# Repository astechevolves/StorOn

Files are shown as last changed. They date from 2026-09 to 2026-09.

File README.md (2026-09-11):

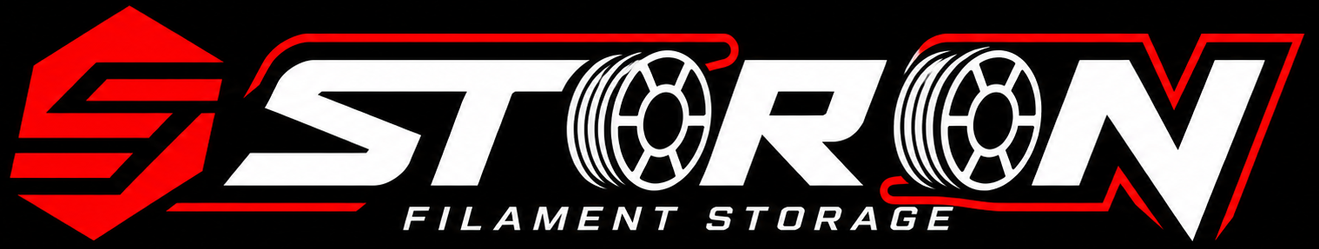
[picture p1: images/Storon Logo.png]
Storon Logo

Name credit to u/akir3y on reddit and chosen based on upvotes.

This project is a Voron printer stand that also stores filament. You have options for active dehumditifcation as well as the ability to feed your Voron (or any other printer really...) from within the stand using a [Filamentalist](https://github.com/Carrot-collective/ERCF_v2/tree/master/Recommended_Options/Filamentalist_Rewinder/Filamentalist_FV3_Rewinder) passive rewinder and an [lll-plus](https://mellow.klipper.cn/en/docs/category/fly-lll-plus-%E7%BC%93%E5%86%B2%E5%99%A8) buffer.

This is rev 1 and i have lots of ideas for what it could be. I am current working on the BOM for the build as it stand and getting the models made so far prepped for upload. 

At the dimensions used for my build there can be up to 14 spools on each drawer and i have 2 drawers installed for a total of 28 spools of storage. I have 5 spools across the top for the toolheads and the buffers are mounted below them. Using [custom lll-plus firmware](https://github.com/astechevolves/lll-buffed) with I2C controls i am connecting a single USB cable to the RasPi running klipper and controlling/monitoring the buffers. 

Some used parts:\
Rack Slides: I did not purchase any as i had some on hand. If i build another one ill need to buy some to test fits. \
2020 Aluminum Extrusion: https://a.co/d/0fAiQeXf \
2040 Aluminum Extrusion: https://a.co/d/03j1iFax \
Corner Brackets: https://a.co/d/0c3Umoue \
3 Side Corners: https://a.co/d/0ic4IAEs \
Profile L Brackets: https://a.co/d/0b12QCzn \
M5 Nuts and Screws: https://a.co/d/0fcr5ywm \
Sealing Foam: https://a.co/d/0fpPBf9j

Hardware for [Clicky Clack Door](https://github.com/tanaes/whopping_Voron_mods/blob/main/clickyclacky_door%2FREADME.md). Used 3 hinges instead of two and the door panel and sealing was longer for the larger door.  

Pin Bushings for Clicky Clack: https://a.co/d/01oHRWRj

If you want monitoring some ESP32 hardware will likely be needed too. How you monitor that data may change. I am publishing MQTT updates to Home Assistant. 

Power supply for dehumidifier, 3VDC required: https://a.co/d/0h5Y2pVP \
MDL-5 Dehumdifier: https://micro-dehumidifier.com/products-rosahl/membranes/ \
Wiring Break out for I2C Buss on Buffers: https://a.co/d/03XT3YTJ

PTFE Connectors: https://a.co/d/0i8aAcsk

[LLL-Plus Buffer](https://3dmellow.com/products/mellow-lll-plus-filament-buffer-for-diy-3d-printers-klipper-rrf-marlin-material-break-detection-automatic-filament-feeding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), either whole and assembled or a kit and print your own parts. If you want to self assembly a good guide was [written here](https://www.teamfdm.com/forums/topic/7953-mellow-fly-lll-pro-filament-buffer/#comment-33137).

Physical modifications have been made as outlined below and new firmware for I2C control via a single USB connection. 
New Firmware can [be found here](https://github.com/astechevolves/lll-buffed). 
The first mod was making the buttons taller so you can find them blind by reaching under the buffer which is mounted facing down. 
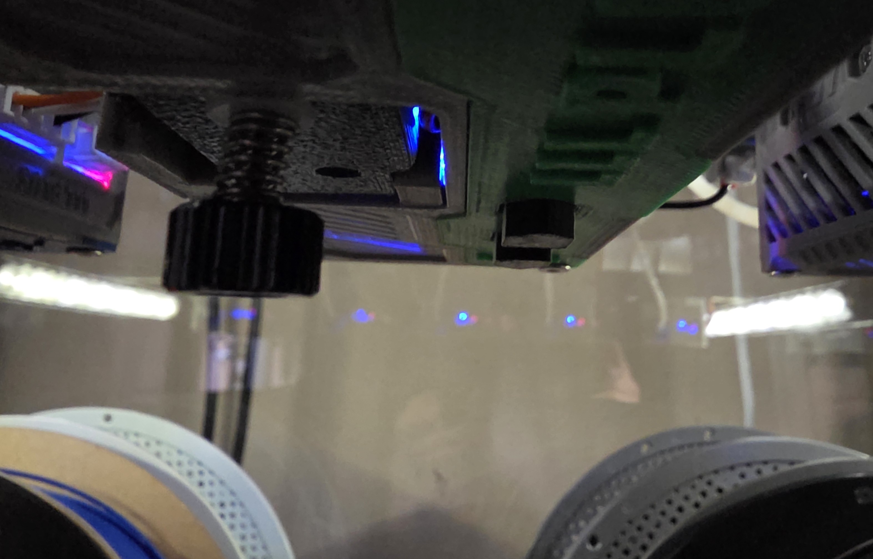
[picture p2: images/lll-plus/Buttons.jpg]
Buttons

The second mod was to change the buffer to allow an ECAS connector. The PTFE tube port was very weak and if the buffer pushed ont he filament at all it would push the tubing out of the connector all together. This was annoying because then the buffer would drop and the filament may feed into the back of the box until the timeout was reached. Not ideal. 
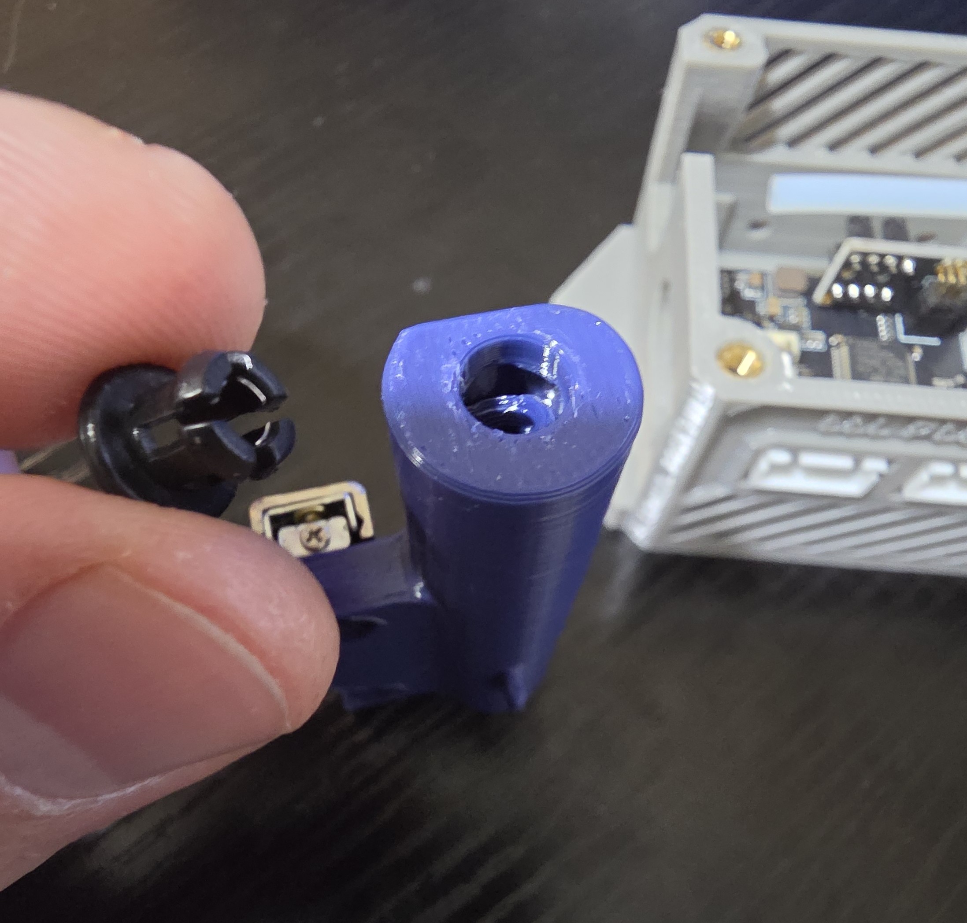
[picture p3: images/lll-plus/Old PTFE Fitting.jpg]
Crappy Collar

The third mod was to install a tougher spring ont he buffer tube. The weak spring meant any resistance ont he filament up to the print could cause sufficient back tension and that would mean the filament stops feeding. A strong spring means you are more likely to make it all the way to the head because it takes more back tension to fully extend the buffer.
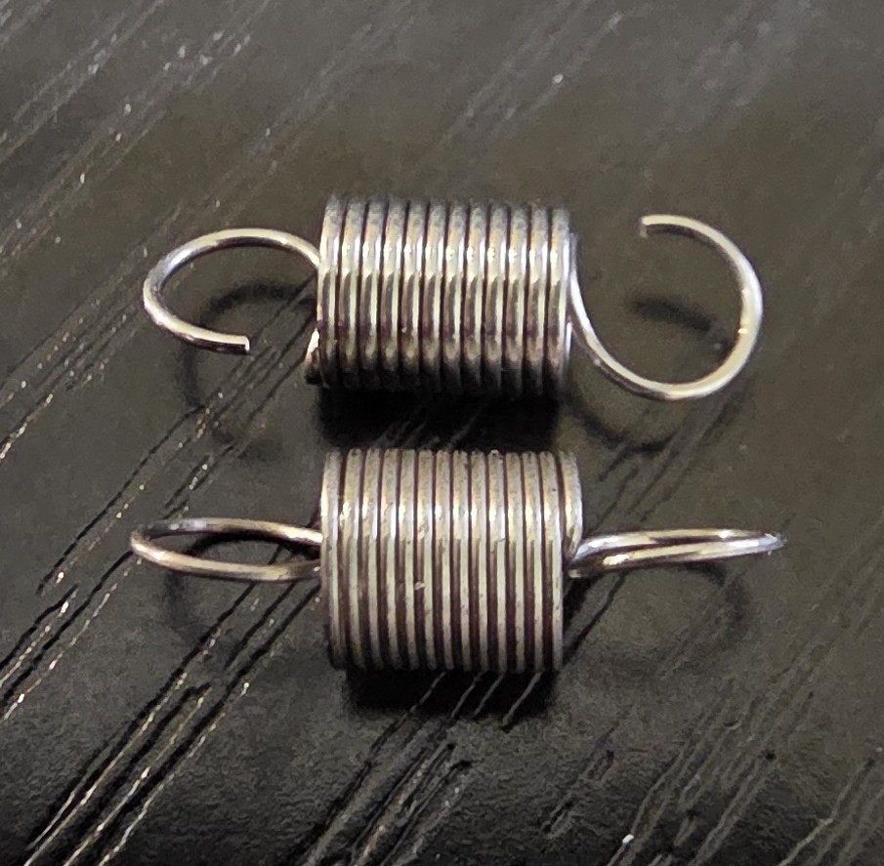
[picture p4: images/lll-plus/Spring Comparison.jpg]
Springs
 

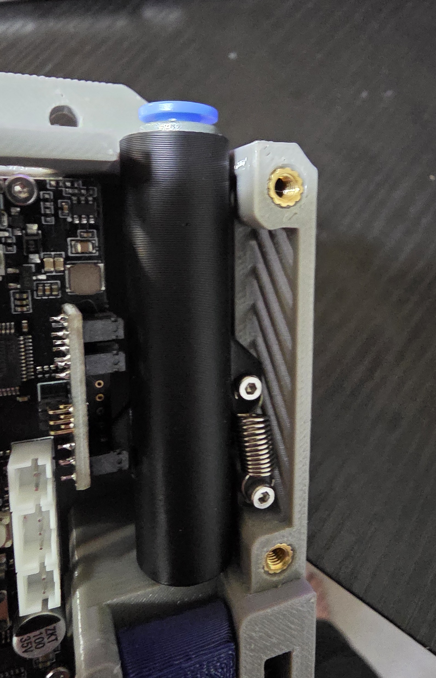
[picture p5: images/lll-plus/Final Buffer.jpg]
With new parts installed


Hardware for [Filmentalist Rollers](https://github.com/Carrot-collective/ERCF_v2/tree/master/Recommended_Options/Filamentalist_Rewinder/Filamentalist_FV3_Rewinder). \
Filamentalist one way bearings: https://a.co/d/0h9YtOMt \
Filamentalist Springs: https://a.co/d/0beVFlb8 \
608 Bearings: https://a.co/d/0bcoLnwL \
688 Bearings: https://a.co/d/02Pbp8nU

Here are some images to give a general idea of the project while i try to get all the other data together and uploaded.

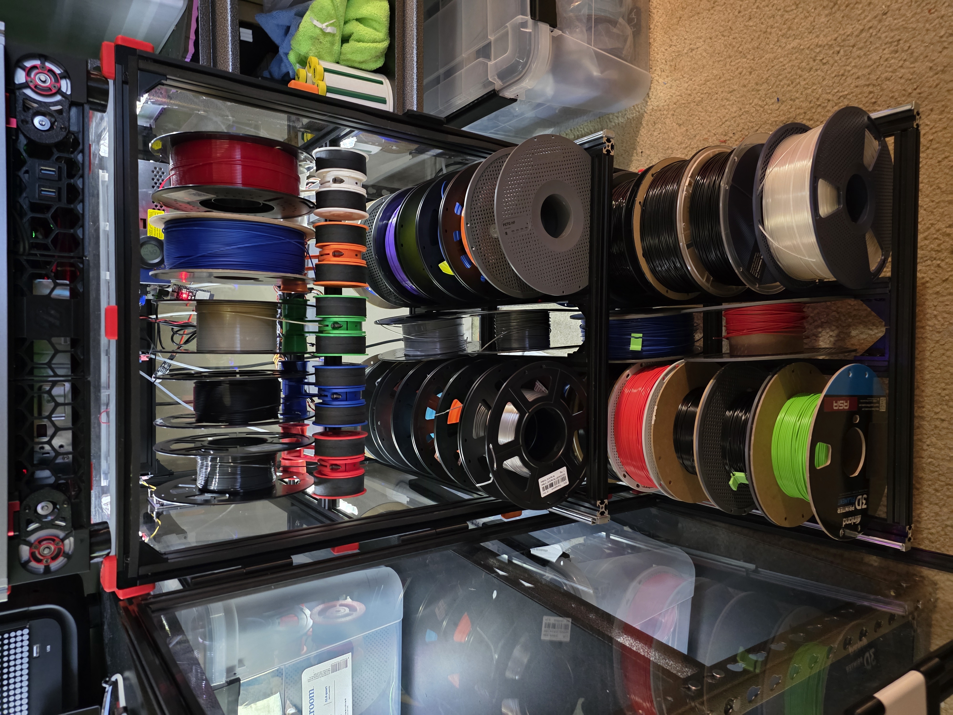
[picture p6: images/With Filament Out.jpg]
With Filament Out


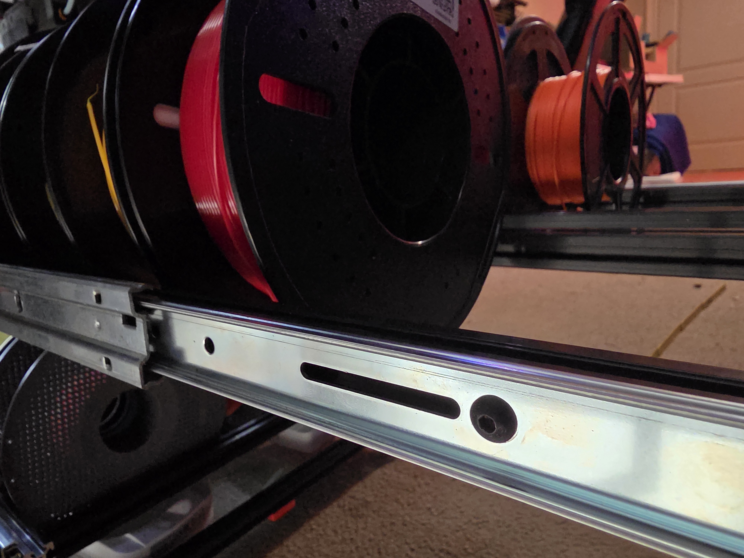
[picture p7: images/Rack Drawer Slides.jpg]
Rack Drawer Slides


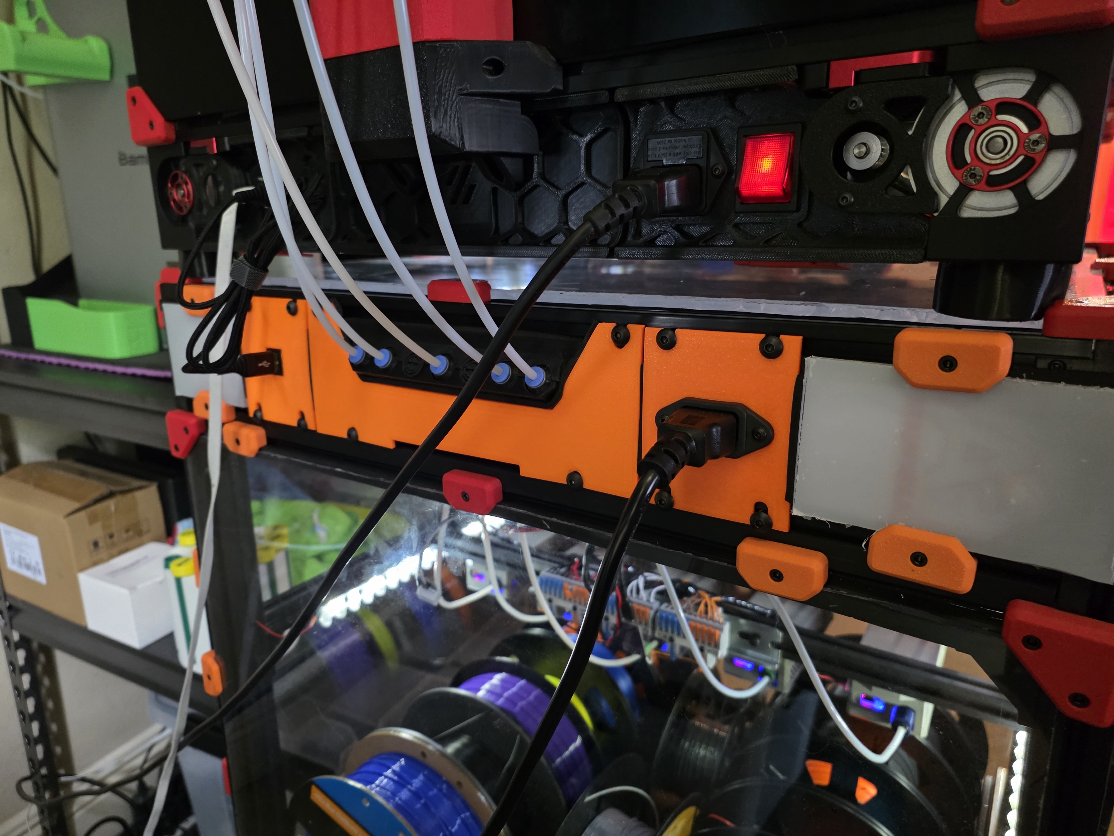
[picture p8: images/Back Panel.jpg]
Back Panel


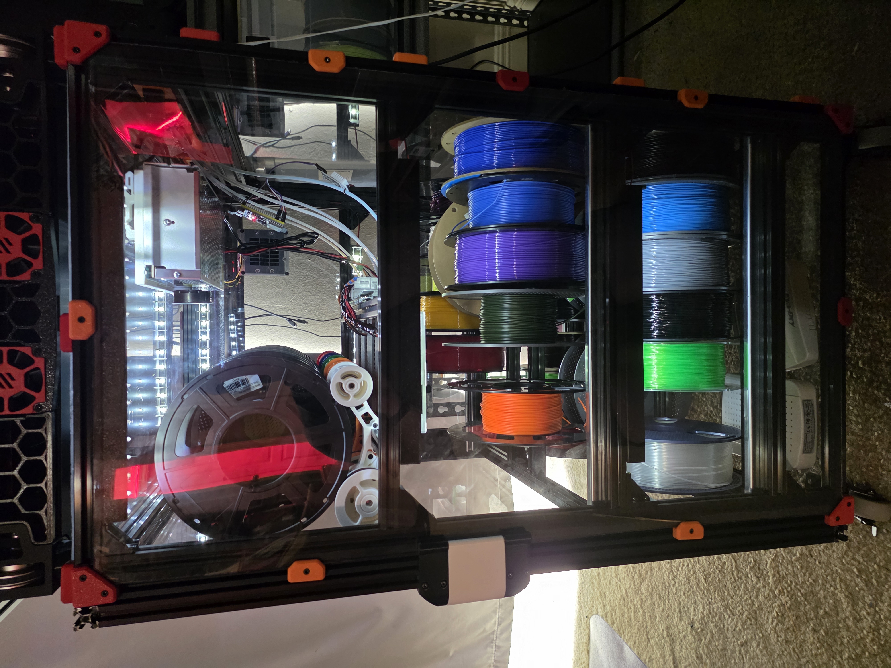
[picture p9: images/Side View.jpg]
Side View


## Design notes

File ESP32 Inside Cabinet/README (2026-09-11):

As a reminder to myself, platformIO build commands:

From the PlatformIO project folder—the one containing platformio.ini—run:

`pio run -t upload`

If PlatformIO doesn’t automatically select the correct serial port:

`pio run -t upload --upload-port COM5`

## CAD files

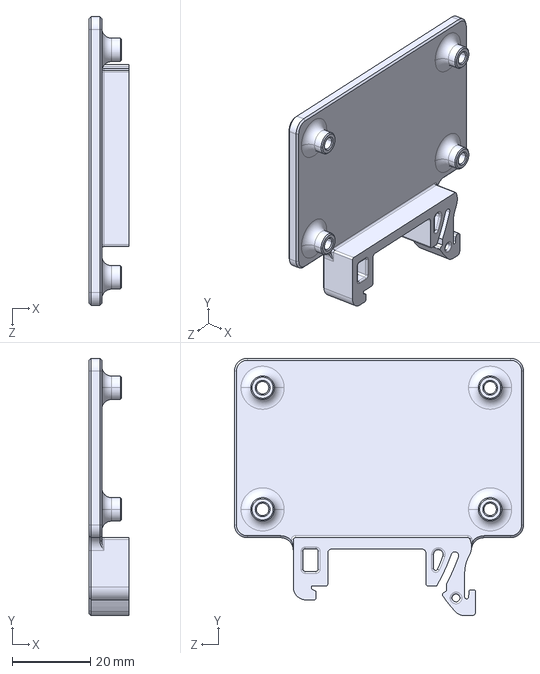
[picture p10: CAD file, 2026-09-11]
CAD/Buck Converter Mount/DIN_RAIL-MOUNT FOR-Buck Converter.STEP
10.2 x 65.6 x 73.7 mm

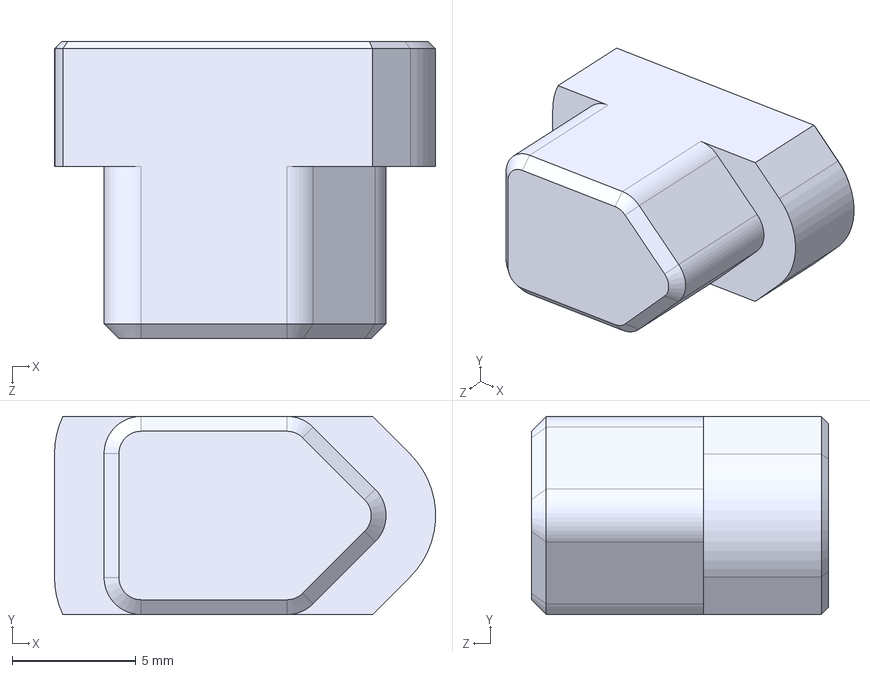
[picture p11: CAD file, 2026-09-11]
CAD/LLL-Plus/Manual Button_Taller.STEP
15.4 x 8.00 x 12.0 mm

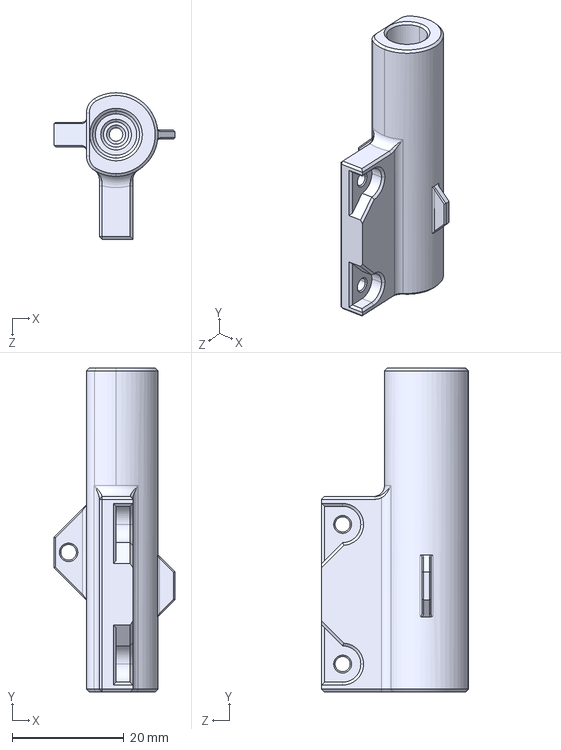
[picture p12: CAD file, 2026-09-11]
CAD/LLL-Plus/Buffer Neck Rebuild rev2.STEP
21.6 x 58.0 x 26.2 mm

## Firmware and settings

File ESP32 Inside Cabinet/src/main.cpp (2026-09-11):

#include <Arduino.h>
#include <WiFi.h>
#include <PubSubClient.h>
#include <DHT.h>
#include <ArduinoJson.h>
#include "../include/config.h"

// ── Pin config ────────────────────────────────────────────
#define DHT_PIN_HIGH 4
#define DHT_PIN_LOW 5
#define DHT_TYPE DHT22

// ── Timing ────────────────────────────────────────────────
#define READ_INTERVAL_MS 30000 // read sensors every 30 seconds

// ── MQTT topic roots ──────────────────────────────────────
#define DEVICE_ID "filament_monitor"
#define TOPIC_HIGH_TEMP DEVICE_ID "/filament_high/temperature"
#define TOPIC_HIGH_HUMIDITY DEVICE_ID "/filament_high/humidity"
#define TOPIC_LOW_TEMP DEVICE_ID "/filament_low/temperature"
#define TOPIC_LOW_HUMIDITY DEVICE_ID "/filament_low/humidity"

// ── Objects ───────────────────────────────────────────────
DHT dhtHigh(DHT_PIN_HIGH, DHT_TYPE);
DHT dhtLow(DHT_PIN_LOW, DHT_TYPE);
WiFiClient wifiClient;
PubSubClient mqtt(wifiClient);

unsigned long lastReadTime = 0;

// ── WiFi ──────────────────────────────────────────────────
void connectWifi()
{
  if (WiFi.status() == WL_CONNECTED)
    return;
  Serial.printf("Connecting to WiFi: %s\n", WIFI_SSID);
  WiFi.begin(WIFI_SSID, WIFI_PASSWORD);
  while (WiFi.status() != WL_CONNECTED)
  {
    delay(500);
    Serial.print(".");
  }
  Serial.printf("\nWiFi connected. IP: %s\n", WiFi.localIP().toString().c_str());
}

// ── HA Discovery ──────────────────────────────────────────
void publishDiscovery(const char *sensorId, const char *sensorName,
                      const char *stateTopic, const char *unit,
                      const char *deviceClass)
{
  char topic[128];
  snprintf(topic, sizeof(topic), "homeassistant/sensor/%s/config", sensorId);

  JsonDocument doc;
  doc["name"] = sensorName;
  doc["state_topic"] = stateTopic;
  doc["unit_of_measurement"] = unit;
  doc["device_class"] = deviceClass;
  doc["state_class"] = "measurement";
  doc["unique_id"] = sensorId;

  JsonObject device = doc["device"].to<JsonObject>();
  device["identifiers"][0] = DEVICE_ID;
  device["name"] = "Filament Monitor";
  device["model"] = "ESP32-S3 + DHT22";
  device["manufacturer"] = "DIY";

  char payload[512];
  serializeJson(doc, payload);

  Serial.printf("Discovery topic: %s\n", topic);
  Serial.printf("Discovery payload: %s\n", payload);

  mqtt.publish(topic, payload, true);
}

void registerSensors()
{
  publishDiscovery("filament_high_temp", "Filament High Temperature",
                   TOPIC_HIGH_TEMP, "°C", "temperature");
  publishDiscovery("filament_high_humidity", "Filament High Humidity",
                   TOPIC_HIGH_HUMIDITY, "%", "humidity");
  publishDiscovery("filament_low_temp", "Filament Low Temperature",
                   TOPIC_LOW_TEMP, "°C", "temperature");
  publishDiscovery("filament_low_humidity", "Filament Low Humidity",
                   TOPIC_LOW_HUMIDITY, "%", "humidity");
  Serial.println("HA discovery published.");
}

// ── MQTT ──────────────────────────────────────────────────
void connectMqtt()
{
  while (!mqtt.connected())
  {
    Serial.print("Connecting to MQTT...");
    if (mqtt.connect(DEVICE_ID, MQTT_USER, MQTT_PASSWORD))
    {
      Serial.println("connected.");
      registerSensors();
    }
    else
    {
      Serial.printf("failed (rc=%d), retrying in 5s\n", mqtt.state());
      delay(5000);
    }
  }
}

// ── Sensor reading ────────────────────────────────────────
void readAndPublish()
{
  float highTemp = dhtHigh.readTemperature();
  float highHum = dhtHigh.readHumidity();
  float lowTemp = dhtLow.readTemperature();
  float lowHum = dhtLow.readHumidity();

  if (!isnan(highTemp) && !isnan(highHum))
  {
    mqtt.publish(TOPIC_HIGH_TEMP, String(highTemp, 1).c_str());
    mqtt.publish(TOPIC_HIGH_HUMIDITY, String(highHum, 1).c_str());
    Serial.printf("High  — Temp: %.1f°C  Humidity: %.1f%%\n", highTemp, highHum);
  }
  else
  {
    Serial.println("Filament High sensor read failed.");
  }

  if (!isnan(lowTemp) && !isnan(lowHum))
  {
    mqtt.publish(TOPIC_LOW_TEMP, String(lowTemp, 1).c_str());
    mqtt.publish(TOPIC_LOW_HUMIDITY, String(lowHum, 1).c_str());
    Serial.printf("Low   — Temp: %.1f°C  Humidity: %.1f%%\n", lowTemp, lowHum);
  }
  else
  {
    Serial.println("Filament Low sensor read failed.");
  }
}

// ── Setup / Loop ──────────────────────────────────────────
void setup()
{
  Serial.begin(115200);
  dhtHigh.begin();
  dhtLow.begin();
  connectWifi();
  mqtt.setServer(MQTT_BROKER, MQTT_PORT);
  mqtt.setBufferSize(1024);
  connectMqtt();
}

void loop()
{
  connectWifi();
  if (!mqtt.connected())
    connectMqtt();
  mqtt.loop();

  unsigned long now = millis();
  if (now - lastReadTime >= READ_INTERVAL_MS)
  {
    lastReadTime = now;
    readAndPublish();
  }
}

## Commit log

2026-09-11 adding some mods and starting to push models
    [Buffer Neck Rebuild rev2.STEP, DIN_RAIL-MOUNT FOR-Buck Converter.STEP, Manual Button_Taller.STEP]
2026-09-20 add 2020 hydrometer bracket
2026-11-04 Add fan and heartbeat led
2026-11-07 StorOn BOM rev1
2026-11-10 ESP32 Web UI and rev1 RFID Reading
2026-11-10 Added webUI documentation for ESP32 kit
2026-11-10 Add wiring for readers
